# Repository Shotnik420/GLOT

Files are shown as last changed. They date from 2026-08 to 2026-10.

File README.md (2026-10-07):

# ✈️ GLOT - Kontroler Lotu RC







GLOT to projekt, którego celem jest stworzenie kontrolera lotu dla samolotów RC z możliwie jak najlepszym stosunkiem jakości do ceny.

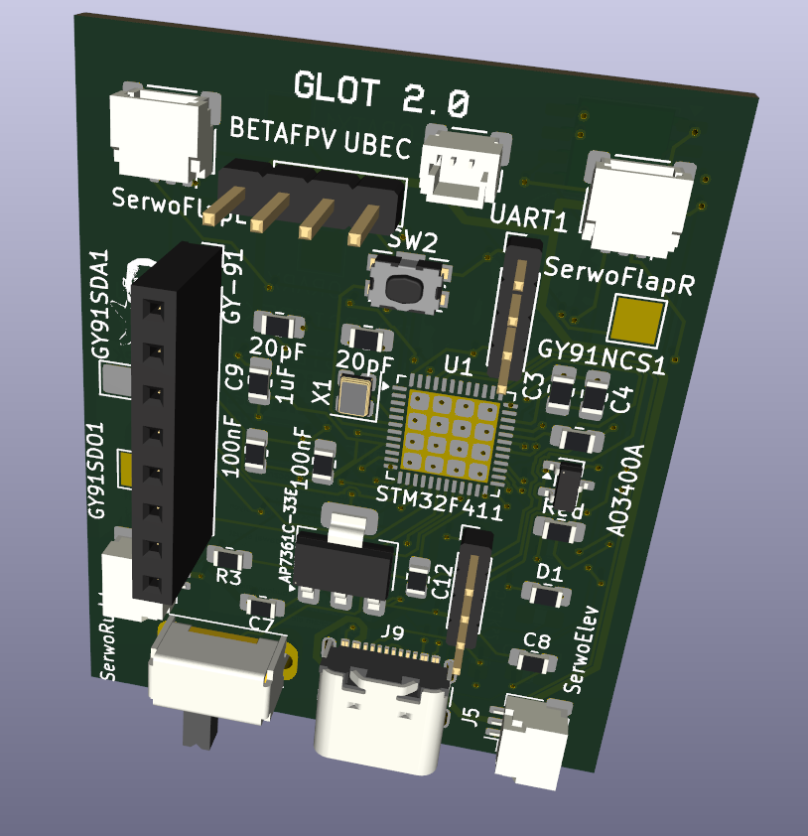
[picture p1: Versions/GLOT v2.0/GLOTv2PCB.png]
GLOT 2.0 PCB


Jest to projekt głównie do naukii podstaw awioniki jak i tworzenia systemów opartych na STM32 i jak radzą sobie w trudnych warunkach.

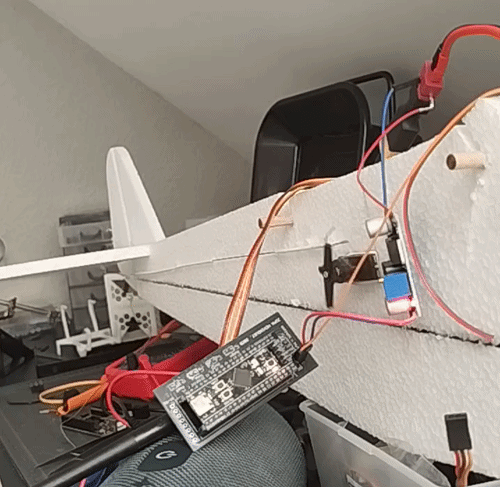
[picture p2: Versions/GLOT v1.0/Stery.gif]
Zlozony zestaw


---

## Wersje
- 📦 **[GLOT v1.0 / 1.5 (Najlepiej udokumentowana)](https://github.com/Shotnik420/GLOT/tree/main/Versions/GLOT%20v1.0)**  
  _Wersja prototypowa._ Pierwsze kroki i weryfikacja koncepcji. Zakończona sukcesem w postaci pierwszego, kilkusekundowego lotu. Pozwoliła zidentyfikować kluczowe problemy z zasilaniem (brownouty), zakłóceniami magistrali I2C i gabarytami płytek. Składała się z dedykowanego nadajnika na ESP32 i odbiornika na STM32.
- ⚡ **[GLOT v2.0 (Obecna wersja)](https://github.com/Shotnik420/GLOT/tree/main/Versions/GLOT%20v2.0)**  
  _Rozwój i optymalizacja._ Najnowsza generacja kontrolera, w której wyciągnięto wnioski z błędów poprzednika. Zoptymalizowano kwestie zasilania serwomechanizmów, poprawiono routing ścieżek na PCB i zmniejszono rozmiary urządzenia, aby lepiej pasowało do ciasnych kadłubów modeli RC.

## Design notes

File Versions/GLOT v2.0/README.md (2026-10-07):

# GLOT 2.0

Druga wersja kontrolera.

Projekt podzielił się na dwa moduły:

- **Nadajnik:** Został zamieniony z własnego systemu na transmiter LiteRadio 2 SE.
- **Odbiornik:** Zamiast gotowej płytki deweloperskiej (jak w v1.0), została zaprojektowana i wykonana **własna autorska płytka PCB**.

Płytka była zainspirowana projektem [DroneController](https://github.com/FPV-Drone-STM32F411/DroneController) i połączenia z niego zostały zapożyczone na pierwsze wersje płytki. Z czasem zostały one zmione lecz autorom tego szablonu, [Evan Bhogel](https://github.com/esb8) oraz [Ammar Mahmood](https://github.com/ammarjmahmood), należy się moje uznanie iż bazowałem na ich projekcie.

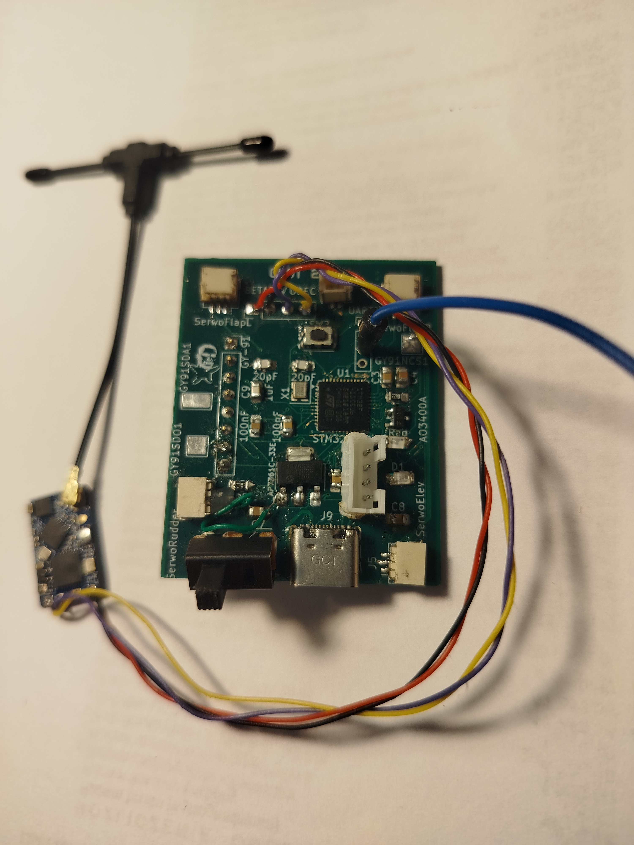
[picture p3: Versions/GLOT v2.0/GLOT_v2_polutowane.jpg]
Polutowany odbiornik GLOT 2.0 PCB

Odbiornik GLOT 2.0 PCB

## Co mamy na pokładzie? (Hardware)

Przejście na dedykowane PCB pozwoliło pozbyć się zbędnego balastu z gotowych modułów i zoptymalizować projekt pod kątem miejsca w ciasnym kadłubie samolotu.

Ta wersja musiała już wznieść samolot na pierwszy porządny lot.

### Kluczowe elementy nowej płytki to m.in.:

| Komponenty                   |
| :--------------------------- |
| STM32F411CEU6                |
| BETAFPV Nano Receiver 2.4GHz |
| GY-91                        |
| IS25LP128 FLASH              |

| Technologie   |
| :------------ |
| C / STM32 HAL |
| I2C           |
| UART          |
| PWM           |

# Podsumowanie wersji

## Co poszło dobrze

- Wgrywanie kodu na mikroprocesor STM32 działało i bezproblemowo wykonywało wszelkie programy.
- Zmiana na 4 warstwową płytkę było niebem a ziemią w kompaktywności układu. Cały układ zajmował 1/3 miejsca która zajmowała wersja 1.0

## Co poszło źle

Czyli czemu im więcej wiesz, tym wiesz ile jeszcze nie wiesz.

- Brak pinu dla gazu silnika bezszczotkowego o, którym zwyczajnie zapomniano. Trzeba było poświęcić pin TX dla UART.
- Słabe rozmieszczenie komponentów na płytce, kondensatory poustawiane niemal losowo co utrudniało lutowanie.
- Kupno LDO o pinoucie innym od planowanego.
- Zbyt niecierpliwe kupno płytki bez wcześniejszej dokładnej inspekcji.

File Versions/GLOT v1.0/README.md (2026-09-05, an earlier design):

# GLOT 1.0 / 1.5

Wersja startowa i pierwsze kroki postawione w kierunku stworzenia w pełni funkcjonalnego prototypu. Pomimo błędów wieku dziecięcego, platformę udało się uruchomić fizycznie, co zaowocowało udanym lotem trwającym 7-8 sekund. Połączyłem wersje 1.0 i 1.5 w jedną sekcję, ponieważ jedyną różnicą między nimi jest płytka PCB, która otrzymała kilka poprawek, kod pozostaje identyczny.

Zdecydowałem się na stworzenie autorskiego nadajnika i odbiornika, aby ominąć koszty drogiej aparatury RC (co dla budżetu studenta jest kluczowe). Projekt podzielił się na dwa moduły:

- **Odbiornik:** Zbudowany na bazie płytki STM32 Blackpill z układem STM32F411CEU6. Moduł nRF24L01+PA+LNA odbiera dane i tłumaczy je na wysterowanie 4 serwomechanizmów oraz prędkość silnika bezszczotkowego (ESC). Na pokładzie znajduje się moduł GY-91 (MPU9250), obsługiwany przez prowizoryczny system PID stabilizujący lot.

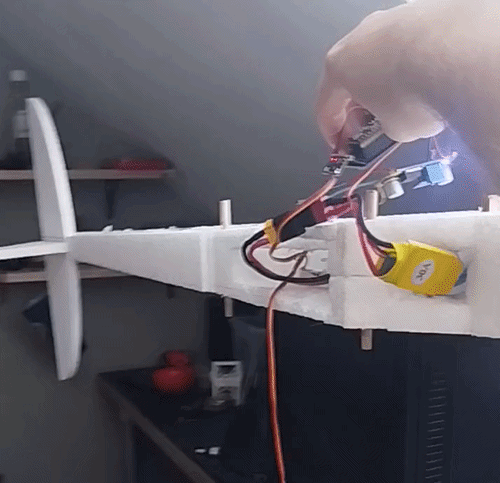
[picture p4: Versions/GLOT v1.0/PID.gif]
Odbiornik


- **Nadajnik:** Oparty na ESP32-S3. Wykorzystuje bibliotekę Bluepad32 do łączenia się z kontrolerem od konsoli przez Bluetooth, a wejścia przesyła w świat za pomocą modułu nRF24L01+PA+LNA. Decyzja o użyciu tak potężnego mikrokontrolera i sporych komponentów z tzw. "szuflady" sprawiła, że układ stał się dość masywny.

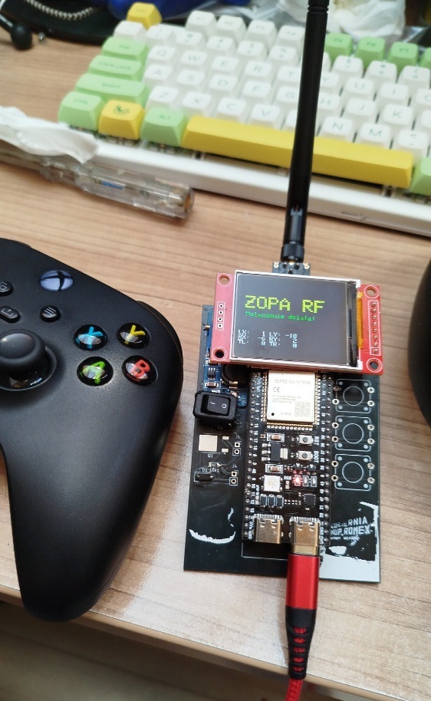
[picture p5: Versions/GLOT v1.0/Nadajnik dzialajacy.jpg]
Nadajnik


---

## Użyte technologie

| Technologia / Komponent | Opis i zastosowanie w projekcie |
| :--- | :--- |
| **C / STM32 HAL** | Główny język i biblioteka sprzętowa użyta do zaprogramowania mikrokontrolera STM32. |
| **I2C** | Protokół komunikacyjny użyty do odczytu danych z modułu GY-91 (akcelerometr/żyroskop). |
| **SPI** | Szybka magistrala użyta do obsługi modułu radiowego nRF24L01+PA+LNA. |
| **PWM (Timery)** | Sprzętowe generowanie sygnałów (TIM2, TIM3) sterujących serwami i silnikiem bezszczotkowym. |
| **USB CDC** | Wirtualny port COM (USB) wykorzystany do wygodnego przesyłania logów i debugowania. |
| **Algorytm PID** | Regulator (Proporcjonalno-Całkująco-Różniczkujący) wyliczający korekty lotek i steru wysokości. |

---

## Podsumowanie testów

### Odbiornik

### Co poszło dobrze

- Pisanie kodu w .C dla STM'a okazało się zaskakująco proste i przyjemne. Stworzyłem całkiem dobry system, który posiadał odbieranie danych radiowych i przekazywanie dostarczonych wartości na zakres serw. Jest prowizoryczny PID (Prioporcjonalno-całkująco-różniczkujący), który jednak jest tak skomplikowany że nie przyznam się do jego napisania, a zawdzięczam go Gemini od Google'a, lecz jest to jeden z moich celów na następne wersje by go zrozumieć i napisać raz jeszcze.

### Co poszło ŹLE

- Połączenie prądu serw z prądem układu sterowniczego. STM32 brownoutował za każdym mocniejszym pociągnieciem serwa. Wymagało przecięcia ścieżek i dolutowania osobnej baterii.

- Pomylone ścieżki SDA i SCL dla modułu GY-91. Wymagało przeciecia ścieżek i zrobienia zworek.

- Zbyt słaby prąd dla serw. Uruchomienie wszystkich naraz było niemożliwe.

- Rozmiar płytki był wyraźnie niekorzystny dla budowy samolotu. Za duży.

- Niezabezpieczenie układów przed wsadzeniem ich do ciasnego kokpitu pojazdu spowodowało fizyczne zwarcie i spalenie mikrokontrolera i przetwornicy

### Nadajnik

### Co poszło ŹLE

- Użycie komponentów będących tzw. "pod ręką" przez co płytka nadajnika jest niepotrzebnie duża. Duże przyciski, duży moduł przetwornicy, duży mikrokontroler.

- Dodanie pól na przyciski, których nie musiało tam być bo kontroler realizował wszystkie potrzeby wejścia.

- Pomimo faktu że zrobienie nadajnika na podstawie kontrolera do Xboxa wydawało się fajnym pomysłem to faktyczna realizacja trochę zniechęciła mnie do tej wizji. Częste zerwania połączeń, zmiany bibliotek, zacinający się cały esp32. Zastanowie się nad kupnem faktycznego kontrolera w przyszłości.

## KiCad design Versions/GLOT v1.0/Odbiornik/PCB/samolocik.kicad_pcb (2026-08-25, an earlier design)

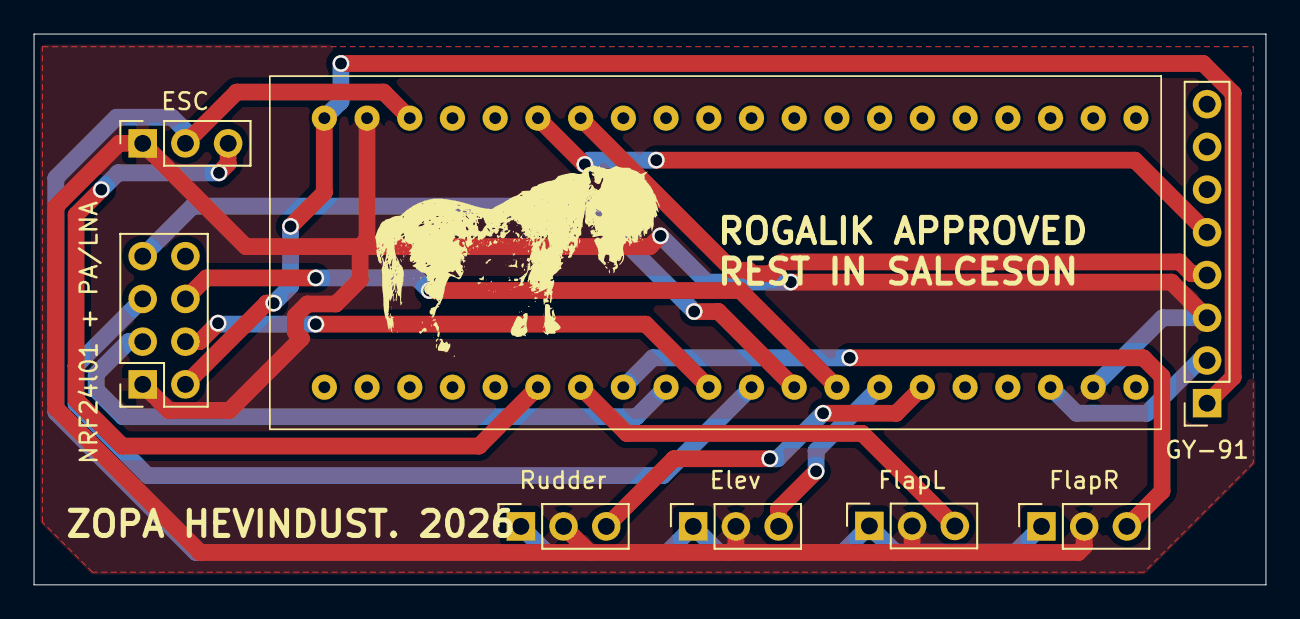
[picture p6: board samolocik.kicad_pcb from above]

Board: 2 copper layers, 73.2 x 32.8 mm, 8 parts (0 on the bottom side), 16 nets.

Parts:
ESC: ESC; PinSocket_1x03_P2.54mm_Vertical
Elev: SerwoElev; PinSocket_1x03_P2.54mm_Vertical
FlapL: SerwoFlapL; PinSocket_1x03_P2.54mm_Vertical
FlapR: SerwoFlapR; PinSocket_1x03_P2.54mm_Vertical
GY-91: GY-91; PinSocket_1x08_P2.54mm_Vertical
NRF24l01 + PA/LNA: Conn_02x04_Odd_Even; PinSocket_2x04_P2.54mm_Vertical
Rudder: SerwoRudder; PinSocket_1x03_P2.54mm_Vertical
STM32BLACKPILL1: stm32

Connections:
GND: ESC.1, Elev.2, FlapL.2, FlapR.2, GY-91.3, NRF24l01 + PA/LNA.1, Rudder.2, STM32BLACKPILL1.4 (G), STM32BLACKPILL1.37 (G)
unnamed: GY-91.1, NRF24l01 + PA/LNA.2, STM32BLACKPILL1.39 (3V3)
unnamed: NRF24l01 + PA/LNA.3, STM32BLACKPILL1.24 (A3)
unnamed: NRF24l01 + PA/LNA.4, STM32BLACKPILL1.22 (A4)
unnamed: NRF24l01 + PA/LNA.5, STM32BLACKPILL1.20 (A5)
unnamed: NRF24l01 + PA/LNA.6, STM32BLACKPILL1.16 (A7)
unnamed: NRF24l01 + PA/LNA.7, STM32BLACKPILL1.18 (A6)
unnamed: GY-91.2, STM32BLACKPILL1.6 (3V3)
unnamed: GY-91.4, STM32BLACKPILL1.27 (B6)
unnamed: GY-91.5, STM32BLACKPILL1.29 (B7)
unnamed: ESC.2, Elev.1, FlapL.1, FlapR.1, Rudder.1, STM32BLACKPILL1.35 (5V)
unnamed: ESC.3, STM32BLACKPILL1.30 (A0)
unnamed: Rudder.3, STM32BLACKPILL1.12 (B1)
unnamed: Elev.3, STM32BLACKPILL1.14 (B0)
unnamed: FlapL.3, STM32BLACKPILL1.28 (A1)
unnamed: FlapR.3, STM32BLACKPILL1.26 (A2)

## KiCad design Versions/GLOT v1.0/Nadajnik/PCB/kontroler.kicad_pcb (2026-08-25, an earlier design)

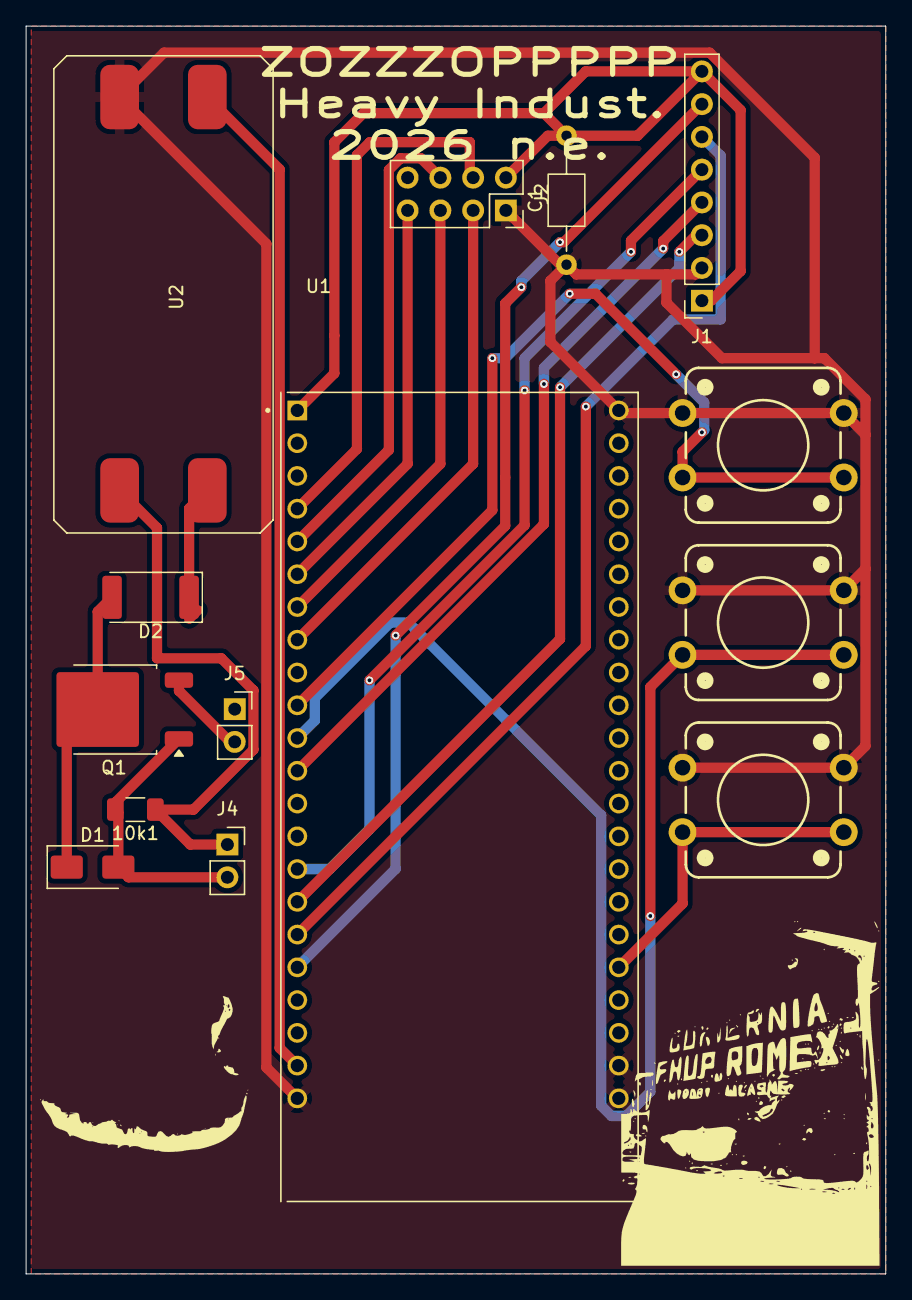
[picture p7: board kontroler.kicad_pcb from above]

Board: 2 copper layers, 66.7 x 96.8 mm, 14 parts (0 on the bottom side), 21 nets.

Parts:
10k1: R; R_1206_3216Metric_Pad1.30x1.75mm_HandSolder
C1: C; C_Axial_L3.8mm_D2.6mm_P10.00mm_Horizontal
D1: SS24; D_SMA
D2: Red; LED_2512_6332Metric_Pad1.52x3.35mm_HandSolder
J1: ekran; PinSocket_1x08_P2.54mm_Vertical
J2: NRF24; PinSocket_2x04_P2.54mm_Vertical
J4: HW-373 OUT; PinSocket_1x02_P2.54mm_Vertical
J5: HW-373 B; PinSocket_1x02_P2.54mm_Vertical
Q1: IRFR9020; TO-252-2
SW1: btn1; Push_PTH_12x12mm
SW2: btn2; Push_PTH_12x12mm
SW3: btn3; Push_PTH_12x12mm
U1: ESP32-S3-DEVKITC-1-N8R2; ESPS3WIDE
U2: hw-045

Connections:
3V3: C1.2, J1.1, J1.8, J2.2, U1.J1_1 (3V3), U1.J1_2 (3V3)
GND: C1.1, J1.2, J2.1, SW1.1, SW2.1, SW3.1, U1.J1_22 (GND), U1.J3_1 (GND), U1.J3_21 (GND), U1.J3_22 (GND), U2.3 (VOUT-)
unnamed: 10k1.2, D1.2 (A), J4.2, Q1.1 (G)
unnamed: D1.1 (K), D2.2 (A), Q1.2 (D)
unnamed: D2.1 (K), U2.1 (VIN+)
unnamed: J1.3, U1.J1_16 (GPIO10)
unnamed: J1.4, U1.J1_12 (GPIO8)
unnamed: J1.5, U1.J1_15 (GPIO9)
unnamed: J1.6, U1.J1_17 (GPIO11)
unnamed: J1.7, U1.J1_18 (GPIO12)
unnamed: J2.3, U1.J1_8 (GPIO15)
unnamed: J2.4, U1.J1_4 (GPIO4)
unnamed: J2.5, U1.J1_7 (GPIO7)
unnamed: J2.6, U1.J1_5 (GPIO5)
unnamed: J2.7, U1.J1_6 (GPIO6)
unnamed: 10k1.1, J4.1, U2.2 (VIN-)
unnamed: J5.2, Q1.3 (S)
unnamed: U1.J1_21 (5V0), U2.4 (VOUT-)
unnamed: SW1.2, U1.J1_10 (GPIO17)
unnamed: SW2.2, U1.J1_11 (GPIO18)
unnamed: SW3.2, U1.J3_18 (GPIO21)

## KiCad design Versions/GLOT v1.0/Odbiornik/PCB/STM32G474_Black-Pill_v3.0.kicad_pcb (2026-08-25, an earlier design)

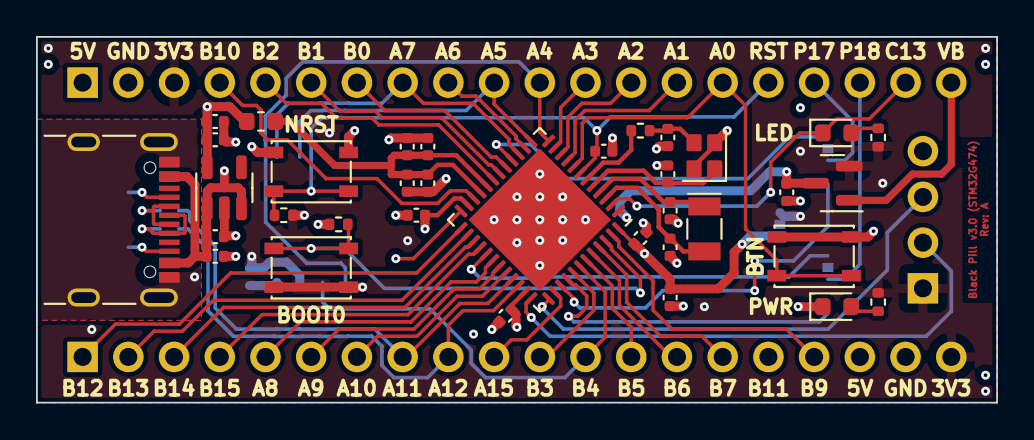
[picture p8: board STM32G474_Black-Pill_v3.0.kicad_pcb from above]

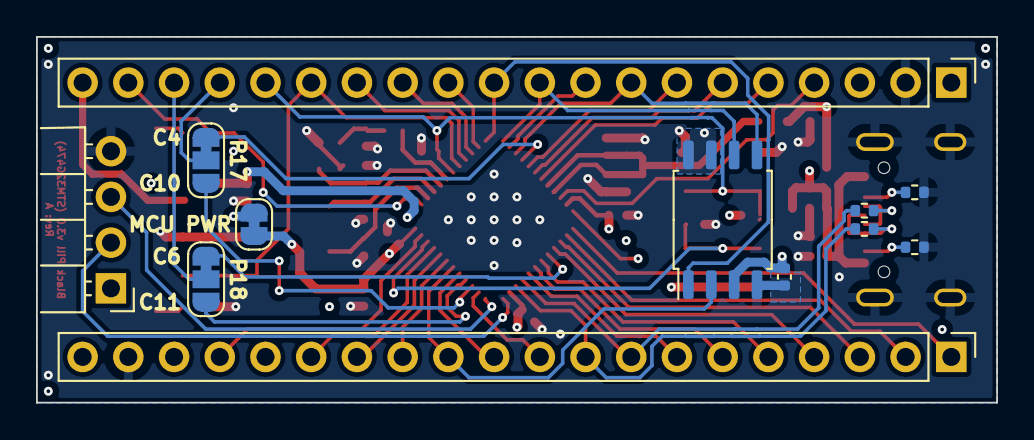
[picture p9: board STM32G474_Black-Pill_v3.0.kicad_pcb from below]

Board: 4 copper layers, 53.3 x 20.3 mm, 47 parts (12 on the bottom side), 58 nets.

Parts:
C101, C104, C108, C109, C110, C112, C114, C115, C119, C120: 100nF; C_0402_1005Metric
C102, C103, C105, C106: 6pF; C_0402_1005Metric
C107: 10µF; C_0402_1005Metric
C113, C116, C117, C118: 1µF; C_0402_1005Metric
D101: red; LED_0603_1608Metric
D102: BAT54C; SOT-23
D103: green; LED_0603_1608Metric
J101: USB_C_Receptacle_USB2.0; USB_C_Receptacle_GCT_USB4105-xx-A_16P_TopMnt_Horizontal
J102, J103: Conn_01x20; PinHeader_1x20_P2.54mm_Vertical
J104: Conn_01x04; PinHeader_1x04_P2.54mm_Horizontal_Board_Edge
JP101, JP102: SolderJumper_3_Bridged12; SolderJumper-3_P1.3mm_Bridged12_RoundedPad1.0x1.5mm_NumberL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
JP103: SolderJumper_2_Bridged; SolderJumper-2_P1.3mm_Bridged_RoundedPad1.0x1.5mm
L101: 10µH; L_0603_1608Metric
R101, R102: 5.1k; R_0402_1005Metric
R103, R108: 10k; R_0402_1005Metric
R104, R105: 10R; R_0402_1005Metric
R106: 0R; R_0402_1005Metric
R107, R109: 100R; R_0402_1005Metric
SW101, SW102, SW103: SW_Push; SW_SPST_PTS810
U101: W25Q32JVSS; SOIC-8_5.23x5.23mm_P1.27mm
U102: STM32G474CEUx; QFN-48-1EP_7x7mm_P0.5mm_EP5.6x5.6mm
U103: AP7343xx; SOT-23-5
Y101: 24MHz; Crystal_SMD_SeikoEpson_FA128-4Pin_2.0x1.6mm
Y102: 32.768kHz; Crystal_SMD_MicroCrystal_CC7V-T1A-2Pin_3.2x1.5mm

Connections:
+3.3V: C101.1, C115.1, C116.1, D102.2, J102.20, J103.3, J104.1, JP103.2 (B), L101.1, R103.1, R107.1, R109.1, SW102.2, U101.3 (IO2), U101.7 (IO3), U101.8 (VCC), U103.5 (OUT)
+5V: C113.1, C114.1, J101.A4 (VBUS), J101.A9 (VBUS), J101.B4 (VBUS), J101.B9 (VBUS), J102.18, J103.1, U103.1 (IN), U103.3 (EN)
/+3.3V_{MCU}: C107.1, C108.1, C109.1, C110.1, JP103.1 (A), U102.23 (VDD), U102.35 (VDD), U102.48 (VDD)
/PA0: J103.15, SW103.2, U102.8 (PA0)
/PA1: J103.14, U102.9 (PA1)
/PA2: J103.13, U102.10 (PA2)
/PA3: J103.12, U102.11 (PA3)
/PA4: J103.11, U101.1 (~CS), U102.12 (PA4)
/PA5: J103.10, U101.6 (CLK), U102.13 (PA5)
/PA6: J103.9, U102.14 (PA6)
/PA7: J103.8, U101.5 (DI(IO0)), U102.15 (PA7)
/PA8: J102.5, U102.30 (PA8)
/PA9: J102.6, U102.31 (PA9)
/PA10: J102.7, U102.32 (PA10)
/PA11: J102.8, R104.2, U102.33 (PA11)
/PA12: J102.9, R105.2, U102.34 (PA12)
/PA15: J102.10, U102.38 (PA15)
/PB0: J103.7, U102.17 (PB0)
/PB1: J103.6, U102.18 (PB1)
/PB2: J103.5, U102.19 (PB2)
/PB3: J102.11, U102.41 (PB3)
/PB4: J102.12, U101.2 (DO(IO1)), U102.42 (PB4)
/PB5: J102.13, U102.43 (PB5)
/PB6: J102.14, U102.44 (PB6)
/PB7: J102.15, U102.45 (PB7)
/PB8: R108.1, SW102.1, U102.46 (PB8)
/PB9: J102.17, U102.47 (PB9)
/PB10: J103.4, U102.22 (PB10)
/PB11: J102.16, U102.24 (PB11)
/PB12: J102.1, U102.25 (PB12)
/PB13: J102.2, U102.26 (PB13)
/PB14: J102.3, U102.27 (PB14)
/PB15: J102.4, U102.28 (PB15)
/PC4: JP101.1 (A), U102.16 (PC4)
/PC6: JP102.1 (A), U102.29 (PC6)
/PC10: JP101.3 (B), U102.39 (PC10)
/PC11: JP102.3 (B), U102.40 (PC11)
/PC13: D103.1 (K), J103.19, U102.2 (PC13)
/PC14: C105.2, U102.3 (PC14), Y102.2
/PC15: C106.2, U102.4 (PC15), Y102.1
/Pin17: J103.17, JP101.2 (C)
/Pin18: J103.18, JP102.2 (C)
/SWCLK: J104.3, U102.37 (PA14)
/SWDIO: J104.2, U102.36 (PA13)
GND: C101.2, C102.1, C103.1, C104.2, C105.1, C106.1, C107.2, C108.2, C109.2, C110.2, C112.2, C113.2, C114.2, C115.2, C116.2, C117.1, C118.1, C119.1, C120.1, D101.1 (K), J101.A1 (GND), J101.A12 (GND), J101.B1 (GND), J101.B12 (GND), J101.S1 (SHIELD), J102.19, J103.2, J104.4, R101.2, R102.2, R108.2, SW101.1, SW103.1, U101.4 (GND), U102.49 (VSS), U103.2 (GND), Y101.2, Y101.4
NRST: C104.1, J103.16, R103.2, SW101.2, U102.7 (PG10)
unnamed: C103.2, R106.2, Y101.3
unnamed: D101.2 (A), R107.2
unnamed: D103.2 (A), R109.2
unnamed: J101.A5 (CC1), R101.1
unnamed: J101.B5 (CC2), R102.1
unnamed: J101.A6 (D+), J101.B6 (D+), R105.1
unnamed: J101.A7 (D-), J101.B7 (D-), R104.1
unnamed: C102.2, U102.5 (PF0), Y101.1
unnamed: R106.1, U102.6 (PF1)
VB: D102.1, J103.20
VBAT: C112.1, D102.3, U102.1 (VBAT)
VDDA: C117.2, C118.2, C119.2, C120.2, L101.2, U102.20 (VREF+), U102.21 (VDDA)

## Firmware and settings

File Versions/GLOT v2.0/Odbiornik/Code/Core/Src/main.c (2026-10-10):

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
/* Includes ------------------------------------------------------------------*/
#include "main.h"
#include "usb_device.h"

/* USER CODE BEGIN Includes */
#include "usbd_cdc_if.h"
#include "controls.h"
#include "pid.h"
#include <math.h>
/* USER CODE END Includes */

SPI_HandleTypeDef hspi1;
SPI_HandleTypeDef hspi2;

TIM_HandleTypeDef htim1;
TIM_HandleTypeDef htim2;
TIM_HandleTypeDef htim3;
TIM_HandleTypeDef htim4;
TIM_HandleTypeDef htim11;

UART_HandleTypeDef huart2;

/* USER CODE BEGIN PV */
uint8_t rx_byte = 0;
uint8_t crsf_buffer[64];  // Bufor na całą paczkę CRSF
uint8_t crsf_index = 0;   // Licznik odebranych bajtów
volatile uint16_t roll, pitch, throttle, yaw;

PIDControls pid_roll;
PIDControls pid_pitch;

uint32_t last_blink_time = 0;
uint32_t last_pid_time = 0;

// --- Zmienne globalne do podglądu w Live Expressions ---
IMU_Data_t sensor_data;
float setpoint_roll, setpoint_pitch;
float pid_out_roll, pid_out_pitch;
long pwm_elev, pwm_flapL, pwm_flapR, pwm_rudder, pwm_throttle;

float angle_roll = 0.0f;
float angle_pitch = 0.0f;

// Zmienne na to, co wyliczy sam akcelerometr
float accel_roll = 0.0f;
float accel_pitch = 0.0f;
/* USER CODE END PV */

void SystemClock_Config(void);
static void MX_GPIO_Init(void);
static void MX_SPI1_Init(void);
static void MX_TIM2_Init(void);
static void MX_TIM3_Init(void);
static void MX_TIM11_Init(void);
static void MX_SPI2_Init(void);
static void MX_TIM4_Init(void);
static void MX_USART2_UART_Init(void);
static void MX_TIM1_Init(void);
/* USER CODE BEGIN 0 */
long map(long x, long in_min, long in_max, long out_min, long out_max) {
    return (x - in_min) * (out_max - out_min) / (in_max - in_min) + out_min;
}
/* USER CODE END 0 */

/**
  * @brief  The application entry point.
  * @retval int
  */
int main(void)
{

  /* MCU Configuration--------------------------------------------------------*/

  /* Reset of all peripherals, Initializes the Flash interface and the Systick. */
  HAL_Init();

  /* Configure the system clock */
  SystemClock_Config();

  /* Initialize all configured peripherals */
  MX_GPIO_Init();
  MX_SPI1_Init();
  MX_TIM2_Init();
  MX_TIM3_Init();
  MX_TIM11_Init();
  MX_SPI2_Init();
  MX_TIM4_Init();
  MX_USART2_UART_Init();
  MX_USB_DEVICE_Init();
  MX_TIM1_Init();

  /* USER CODE BEGIN 2 */
    // --- 1. WYMUSZENIE CZĘSTOTLIWOŚCI (50 Hz) ---
    __HAL_TIM_SET_AUTORELOAD(&htim4, 19999);
    TIM1->PSC = 99; // Naprawa TIM1

    // --- 2. TWARDE PRZYPISANIE PINÓW ---
    GPIO_InitTypeDef GPIO_InitStruct = {0};
    __HAL_RCC_GPIOA_CLK_ENABLE();
    __HAL_RCC_GPIOB_CLK_ENABLE();

    GPIO_InitStruct.Mode = GPIO_MODE_AF_PP;
    GPIO_InitStruct.Pull = GPIO_NOPULL;
    GPIO_InitStruct.Speed = GPIO_SPEED_FREQ_LOW;

    // Serwa na porcie B
    GPIO_InitStruct.Pin = GPIO_PIN_10;
    GPIO_InitStruct.Alternate = GPIO_AF1_TIM2;
    HAL_GPIO_Init(GPIOB, &GPIO_InitStruct); // Prawa klapa

    GPIO_InitStruct.Pin = GPIO_PIN_1;
    GPIO_InitStruct.Alternate = GPIO_AF2_TIM3;
    HAL_GPIO_Init(GPIOB, &GPIO_InitStruct); // Kierunek

    GPIO_InitStruct.Pin = GPIO_PIN_8 | GPIO_PIN_9;
    GPIO_InitStruct.Alternate = GPIO_AF2_TIM4;
    HAL_GPIO_Init(GPIOB, &GPIO_InitStruct); // Wysokość i Lewa Klapa

    // Silnik na PA9 (TIM1_CH2)
    GPIO_InitStruct.Pin = GPIO_PIN_9;
    GPIO_InitStruct.Alternate = GPIO_AF1_TIM1;
    HAL_GPIO_Init(GPIOA, &GPIO_InitStruct); // THROTTLE / ESC

    // --- 3. RĘCZNA KONFIGURACJA TIM1_CH2 ---
    TIM_OC_InitTypeDef sConfigOC_TIM1 = {0};
    sConfigOC_TIM1.OCMode = TIM_OCMODE_PWM1;
    sConfigOC_TIM1.Pulse = 1000; // Pozycja startowa = zero gazu
    sConfigOC_TIM1.OCPolarity = TIM_OCPOLARITY_HIGH;
    sConfigOC_TIM1.OCFastMode = TIM_OCFAST_DISABLE;
    HAL_TIM_PWM_ConfigChannel(&htim1, &sConfigOC_TIM1, TIM_CHANNEL_2);

    // --- 4. START KOMUNIKACJI I TIMERÓW ---
    HAL_UART_Receive_IT(&huart2, &rx_byte, 1);

    HAL_TIM_PWM_Start(&htim2, TIM_CHANNEL_3);
    HAL_TIM_PWM_Start(&htim3, TIM_CHANNEL_4);
    HAL_TIM_PWM_Start(&htim4, TIM_CHANNEL_3);
    HAL_TIM_PWM_Start(&htim4, TIM_CHANNEL_4);

    // Start silnika + aktywacja wyjść (MOE) dla zaawansowanego TIM1
    HAL_TIM_PWM_Start(&htim1, TIM_CHANNEL_2);
    __HAL_TIM_MOE_ENABLE(&htim1);
    TIM1->CCR2 = 1000; // Zabezpieczenie (0% gazu)

    // Inicjalizacja PID
    PID_Init(&pid_roll, 0.5f, 0.0f, 0.0f, 100.0f, 300.0f);
    PID_Init(&pid_pitch, 0.5f, 0.0f, 0.0f, 100.0f, 300.0f);

    // Inicjalizacja GY-91 (MPU9250) - BARDZO WAŻNE
    MPU9250_Init();

    last_pid_time = HAL_GetTick();
    // Czekamy 2 sekundy, aż ESC zagra melodyjkę i zniknie pikanie
    HAL_Delay(2000);
  /* USER CODE END 2 */

  /* Infinite loop */
  /* USER CODE BEGIN WHILE */
    while (1)
    {
        // 1. Mruganie diodą (wizualny wskaźnik, że kod nie wisi)
        if (HAL_GetTick() - last_blink_time >= 300)
        {
            HAL_GPIO_TogglePin(GPIOA, LED_Pin);
            last_blink_time = HAL_GetTick();
        }

        // 2. Obliczenie delty czasu (dt) w sekundach dla PID
        uint32_t current_time = HAL_GetTick();
        float dt = (current_time - last_pid_time) / 1000.0f;
        last_pid_time = current_time;

        // Zabezpieczenie przed błędem matematycznym
        if(dt <= 0.0f) dt = 0.001f;

        // 3. Odczyt danych z żyroskopu i akcelerometru
        MPU9250_Read(&sensor_data);

        // 4. Przeliczenie sygnałów z CRSF na oczekiwaną prędkość obrotu (Setpoints)
        //setpoint_roll = (roll - 992.0f) * 0.18f;
        //setpoint_pitch = (pitch - 992.0f) * 0.18f;

        // SYMULACJA BEZ KONTROLERA RC:
        setpoint_roll = 0.0f;   // Chcę, żeby samolot był płasko (0 stopni) w osi Roll
        setpoint_pitch = 10.0f; // Chcę, żeby samolot miał nos 10 stopni w górę w osi Pitch

        // Jeśli odbiornik traci zasięg (drążki spadają blisko 0)
        if (roll < 100) setpoint_roll = 0.0f;
        if (pitch < 100) setpoint_pitch = 0.0f;

        // 5. Obliczenie wartości stabilizujących przez PID
        pid_out_roll = PID_Compute(&pid_roll, setpoint_roll, sensor_data.gyro_x, dt);
        pid_out_pitch = PID_Compute(&pid_pitch, setpoint_pitch, sensor_data.gyro_y, dt);

        // 6. MIKSER (Zamiana wyjść z PID na sygnały PWM)
        pwm_elev = 1500 + (long)pid_out_pitch;

        // Lotki działają przeciwbieżnie: jedna idzie w górę (+), druga w dół (-)
        pwm_flapL = 1500 + (long)pid_out_roll;
        pwm_flapR = 1500 - (long)pid_out_roll;

        // Kierunek (Rudder) i Throttle zostawiamy na razie w trybie bezpośrednim
        pwm_rudder = map(yaw, 172, 1811, 1000, 2000);
        pwm_throttle = map(throttle, 172, 1811, 1000, 2000);

        // 7. ZABEZPIECZENIA - obcięcie sygnałów PWM
        if(pwm_elev > 2000) pwm_elev = 2000; else if(pwm_elev < 1000) pwm_elev = 1000;
        if(pwm_flapL > 2000) pwm_flapL = 2000; else if(pwm_flapL < 1000) pwm_flapL = 1000;
        if(pwm_flapR > 2000) pwm_flapR = 2000; else if(pwm_flapR < 1000) pwm_flapR = 1000;
        if(pwm_rudder > 2000) pwm_rudder = 2000; else if(pwm_rudder < 1000) pwm_rudder = 1000;

        // Zabezpieczenie silnika
        if(pwm_throttle > 2000) pwm_throttle = 2000;
        if(throttle < 200) pwm_throttle = 1000; // Awaryjne odcięcie silnika

        // --- OBLICZANIE PRAWDZIWEGO KĄTA (FILTR KOMPLEMENTARNY) ---

        // 1. Akcelerometr wylicza gdzie jest grawitacja (wzór z trygonometrii, 57.2957 to 180/PI)
        accel_pitch = atan2f(-sensor_data.accel_x, sensor_data.accel_z) * 57.2957f;
        accel_roll = atan2f(sensor_data.accel_y, sensor_data.accel_z) * 57.2957f;

        // 2. Filtr komplementarny: Ufa w 98% żyroskopowi (szybkość), a w 2% akcelerometrowi (grawitacja)
        // Zmieniasz angle_... dodając prędkość obrotu z żyroskopu pomnożoną przez czas (dt)
        angle_pitch = 0.98f * (angle_pitch + (sensor_data.gyro_y * dt)) + 0.02f * accel_pitch;
        angle_roll = 0.98f * (angle_roll + (sensor_data.gyro_x * dt)) + 0.02f * accel_roll;
        // 8. Aktualizacja PWM na timerach
        TIM4->CCR3 = (uint32_t)pwm_elev;     // PB8
        TIM4->CCR4 = (uint32_t)pwm_flapL;    // PB9
        TIM2->CCR3 = (uint32_t)pwm_flapR;    // PB10
        TIM3->CCR4 = (uint32_t)pwm_rudder;   // PB1
        TIM1->CCR2 = (uint32_t)pwm_throttle; // PA9
    }
  /* USER CODE END WHILE */

}

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
/* USER CODE BEGIN 4 */
//tu kurwa sie robi gdy dostajemy sygnał kurwa od kontrolera
void HAL_UART_RxCpltCallback(UART_HandleTypeDef *huart)
{
    if (huart->Instance == USART2)
    {
        // Zapisujemy odebrany bajt do bufora
        crsf_buffer[crsf_index] = rx_byte;

        // Jeśli pierwszy bajt to nie jest magiczne 0xC8 (200), to ignorujemy śmieci
        if (crsf_index == 0 && crsf_buffer[0] != 0xC8) {
            crsf_index = 0;
        }
        else {
            crsf_index++;
        }

        // Ramka z kanałami RC w CRSF ma dokładnie 26 bajtów
        if (crsf_index >= 26) {
            // Sprawdzamy czy to ramka z pozycjami drążków (Typ ramki = 0x16)
            if (crsf_buffer[2] == 0x16) {

                // Magia przesunięć bitowych CRSF (rozpakowywanie 11-bitowych danych z 8-bitowych bajtów)
                // Kanał 1 (Roll)
                roll = (uint16_t)((crsf_buffer[3] | crsf_buffer[4] << 8) & 0x07FF);
                // Kanał 2 (Pitch)
                pitch = (uint16_t)((crsf_buffer[4] >> 3 | crsf_buffer[5] << 5) & 0x07FF);
                // Kanał 3 (Throttle)
                throttle = (uint16_t)((crsf_buffer[5] >> 6 | crsf_buffer[6] << 2 | crsf_buffer[7] << 10) & 0x07FF);
                // Kanał 4 (Yaw)
                yaw = (uint16_t)((crsf_buffer[7] >> 1 | crsf_buffer[8] << 7) & 0x07FF);

                // (Opcjonalnie) Kolejne kanały, np. na uzbrajanie silników (AUX1) byłyby dalej
            }
            crsf_index = 0; // Zaczynamy szukać kolejnej ramki od nowa
        }

        // ZNOWU UZBRAJAMY PRZERWANIE na kolejny bajt
        HAL_UART_Receive_IT(&huart2, &rx_byte, 1);
    }
}

void HAL_UART_ErrorCallback(UART_HandleTypeDef *huart)
{
    // W razie błędu na linii ignorujemy zator, resetujemy licznik i nasłuchujemy dalej
    if (huart->Instance == USART2) {
        crsf_index = 0;
        HAL_UART_Receive_IT(&huart2, &rx_byte, 1);
    }
}
/* USER CODE END 4 */
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


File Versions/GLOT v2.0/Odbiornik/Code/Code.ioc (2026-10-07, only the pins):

Mcu.UserName=STM32F411CEUx
PA1.GPIO_Label=LED
PA1.Signal=GPIO_Output
PA11.Signal=USB_OTG_FS_DM
PA12.Signal=USB_OTG_FS_DP
PA2.Signal=USART2_TX
PA3.Signal=USART2_RX
PA4.GPIO_Label=GY91CS
PA4.Signal=GPIO_Output
PA5.Signal=SPI1_SCK
PA6.Signal=SPI1_MISO
PA7.Signal=SPI1_MOSI
PA9.Signal=S_TIM1_CH2
PB1.Signal=S_TIM3_CH4
PB10.Signal=S_TIM2_CH3
PB12.GPIO_Label=FlashCS
PB12.Signal=GPIO_Output
PB13.Signal=SPI2_SCK
PB14.Signal=SPI2_MISO
PB15.Signal=SPI2_MOSI
PB8.Signal=S_TIM4_CH3
PB9.Signal=S_TIM4_CH4

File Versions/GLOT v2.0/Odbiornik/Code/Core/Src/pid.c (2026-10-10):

#include "pid.h"
#include "main.h" // Wymagane, żeby pid.c widziało hspi1 i piny zdefiniowane w CubeMX

// Podpinamy SPI z main.c, żeby funkcje MPU mogły z niego korzystać
extern SPI_HandleTypeDef hspi1;

// --- FUNKCJE PID ---

void PID_Init(PIDControls *pid, float p, float i, float d, float iLim, float sLim) {
    pid->kp = p;
    pid->ki = i;
    pid->kd = d;

    pid->itg = 0.0f;
    pid->prevErr = 0.0f;

    pid->iLimit = iLim;
    pid->servoLimit = sLim;
}

// Zmieniono z void na float, bo funkcja zwraca wartość!
float PID_Compute(PIDControls *pid, float desired, float actual, float dt) {
    float err = desired - actual;

    // Bierzemy proporcje do błędu (P)
    float p_out = pid->kp * err; // Poprawiono 'error' na 'err'

    // Sumujemy błąd w czasie (I)
    pid->itg += err * dt; // Poprawiono 'error' na 'err'

    // Blokada przed zbytnim wychyleniem itg
    if(pid->itg > pid->iLimit) {
        pid->itg = pid->iLimit;
    }
    else if(pid->itg < -pid->iLimit) {
        pid->itg = -pid->iLimit; // Dodano brakujący minus!
    }

    // Proporcjowanie itg
    float i_out = pid->itg * pid->ki;

    // Zmiana błędu w czasie (D)
    float dtv = (err - pid->prevErr) / dt;
    float d_out = dtv * pid->kd;

    pid->prevErr = err;

    float total_out = p_out + i_out + d_out;

    // Blokada przed zbytnim wychyleniem SERWA
    if(total_out > pid->servoLimit) {
        total_out = pid->servoLimit; // Poprawiono 'serwoLimit'
    }
    else if(total_out < -pid->servoLimit) {
        total_out = -pid->servoLimit; // Dodano brakujący minus!
    }

    return total_out;
}

// --- FUNKCJE MPU9250 (GY-91) ---

void MPU9250_WriteReg(uint8_t reg, uint8_t data) {
    uint8_t txData[2];
    txData[0] = reg & 0x7F; // Zerowy bit MSB -> ZAPIS
    txData[1] = data;

    // Upewnij się, że w CubeMX pin nazywa się dokładnie GY91CS_Pin i jest na odpowiednim porcie
    HAL_GPIO_WritePin(GPIOA, GY91CS_Pin, GPIO_PIN_RESET);
    HAL_SPI_Transmit(&hspi1, txData, 2, 10);
    HAL_GPIO_WritePin(GPIOA, GY91CS_Pin, GPIO_PIN_SET);
}

void MPU9250_ReadRegs(uint8_t reg, uint8_t *data, uint8_t len) {
    uint8_t txData = reg | 0x80; // Ustawiony bit MSB -> ODCZYT

    HAL_GPIO_WritePin(GPIOA, GY91CS_Pin, GPIO_PIN_RESET);
    HAL_SPI_Transmit(&hspi1, &txData, 1, 10);
    HAL_SPI_Receive(&hspi1, data, len, 10);
    HAL_GPIO_WritePin(GPIOA, GY91CS_Pin, GPIO_PIN_SET);
}

void MPU9250_Init(void) {
    // Wybudzenie czujnika (PWR_MGMT_1)
    MPU9250_WriteReg(0x6B, 0x00);
    HAL_Delay(100);

    // Filtr dolnoprzepustowy DLPF (CONFIG). Wartość 0x03 to filtr ok. 41Hz. (odcina drgania silnika)
    MPU9250_WriteReg(0x1A, 0x03);

    // Konfiguracja Żyroskopu na ±500 stopni na sekundę (GYRO_CONFIG)
    MPU9250_WriteReg(0x1B, 0x08);

    // Konfiguracja Akcelerometru na ±4g (ACCEL_CONFIG)
    MPU9250_WriteReg(0x1C, 0x08);
}

void MPU9250_Read(IMU_Data_t *imu) {
    uint8_t raw_data[14];

    // Odczyt 14 bajtów zaczynając od rejestru 0x3B (ACCEL_XOUT_H)
    MPU9250_ReadRegs(0x3B, raw_data, 14);

    // Składanie 16-bitowych wartości
    int16_t ax = (raw_data[0] << 8) | raw_data[1];
    int16_t ay = (raw_data[2] << 8) | raw_data[3];
    int16_t az = (raw_data[4] << 8) | raw_data[5];

    int16_t gx = (raw_data[8] << 8) | raw_data[9];
    int16_t gy = (raw_data[10] << 8) | raw_data[11];
    int16_t gz = (raw_data[12] << 8) | raw_data[13];

    // Przeliczenie na wartości fizyczne:
    // Akcelerometr dla ±4g ma czułość 8192 LSB/g
    imu->accel_x = (float)ax / 8192.0f;
    imu->accel_y = (float)ay / 8192.0f;
    imu->accel_z = (float)az / 8192.0f;

    // Żyroskop dla ±500 dps ma czułość 65.5 LSB/dps
    imu->gyro_x = (float)gx / 65.5f;
    imu->gyro_y = (float)gy / 65.5f;
    imu->gyro_z = (float)gz / 65.5f;
}

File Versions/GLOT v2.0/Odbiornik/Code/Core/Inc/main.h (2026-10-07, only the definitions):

#define LED_Pin GPIO_PIN_1
#define LED_GPIO_Port GPIOA
#define GY91CS_Pin GPIO_PIN_4
#define GY91CS_GPIO_Port GPIOA
#define FlashCS_Pin GPIO_PIN_12
#define FlashCS_GPIO_Port GPIOB

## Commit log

2026-08-25 Change 1
    [STM32G474_Black-Pill_v3.0.kicad_pcb, samolocik.kicad_pcb, samolocik.kicad_sch]
2026-08-25 Dodanie ReadMe.md dla GLOT v1.0
    [STM32G474_Black-Pill_v3.0.kicad_pcb, kontroler.kicad_pcb, kontroler.kicad_sch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]
2026-10-09 PID #1
2026-10-10 PID #2

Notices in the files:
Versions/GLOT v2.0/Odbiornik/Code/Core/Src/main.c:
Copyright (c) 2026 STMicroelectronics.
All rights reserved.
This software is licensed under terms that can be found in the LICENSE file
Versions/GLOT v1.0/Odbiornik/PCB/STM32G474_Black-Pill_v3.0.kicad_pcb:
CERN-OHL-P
